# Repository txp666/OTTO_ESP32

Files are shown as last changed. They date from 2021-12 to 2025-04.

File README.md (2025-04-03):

# OTTO_ESP32  此仓库弃用，建议制作 小智AI版本
 OTTO机器人加入esp32蓝牙遥控和屏幕

[OTTO开源地址](https://github.com/OttoDIY)

[OTTO官网](https://www.ottodiy.com/)

[OTTO组装教程](https://tech.limuqiao.com/archives/24.html)

ESP32开发环境：[VScode+PlatformIO](https://blog.csdn.net/qlexcel/article/details/121527415)

安装存储卡、硬件参考[Peak](https://github.com/peng-zhihui/Peak)

采购参考请看HardWare文件夹

[【自制】通过学习稚晖君的Peak做个OTTO机器人【教程】_哔哩哔哩_bilibili](https://www.bilibili.com/video/BV1aq4y1m7bJ?spm_id_from=333.999.0.0)

[【自制】otto机器人移植ESP32+ESP32蓝牙遥控【演示】_哔哩哔哩_bilibili](https://www.bilibili.com/video/BV1ua41167SG?spm_id_from=333.999.0.0)

# 联系我：

若有bug或问题请联系我

QQ:1104428360

邮箱：771454616@qq.com

# 版本更新说明：
**2022/7/8**

程序更新动图播放、无遥控，打开开关跳舞

**2022/5/20**

Model更新、开sd卡槽、头部改变形状

**2022/5/19**

pcb添加sd卡

封装更换为0603（方便新手焊接）

放弃使用蓝牙遥控器

**2022/1/20**

Model->body 增加了开关处的壁厚

HardWare->OTTO修改了舵机排针位置

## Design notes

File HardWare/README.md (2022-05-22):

# 打样：

OTTO的PCB厚度一定要1mm

# 采购：

[电池[303450/500毫安]](https://item.taobao.com/item.htm?spm=a1z09.2.0.0.99af2e8d9avaY7&id=528235852444&_u=p20q7cgbef60)

| Comment | Description | Designator | Footprint | Quantity |
| --- | --- | --- | --- | --- |
| [RAINSUN](https://item.taobao.com/item.htm?spm=a1z09.2.0.0.7caa2e8dtIdJCk&id=558699169012&_u=p20q7cgb121e) | 天线 | A1 | ANT-Rainsun-AN5120 | 1 |
| 0.1uF | Capacitor | C1, C2, C3, C5, C8,  C12, C13 | C0603 | 7 |
| 10uF | Capacitor | C4, C6, C14 | C0603 | 3 |
| 1uF | Capacitor | C7 | C0603 | 1 |
| 4.7UF | Capacitor | C9, C11 | C0603 | 2 |
| 104/0.1uf/100nf | Capacitor | C10 | C0603 | 1 |
| red | led | D1 | LED0603 | 1 |
| [GP26-2520WV-3P](https://item.taobao.com/item.htm?spm=a1z10.3-c-s.w4002-21223910208.18.40c96a4b8Tk4yR&id=540755607552) | 2.54间距3p排针 | H1, H2, H3, H4 | PIN2.54_1*3 | 4 |
| [AO3400A](https://item.taobao.com/item.htm?spm=a1z10.3-c-s.w4002-21223910208.9.43706a4biknwUv&id=522574089119) | N-MOS | Q1, Q2 | SOT23-3 | 2 |
| 0R | Resistor | R2 | R0603 | 1 |
| 200R | Resistor | R3 | R0603 | 1 |
| 12K | Resistor | R4, R5 | R0603 | 2 |
| 10K | Resistor | R6, R14, R15, R16,  R17, R18, R19, R20 | R0603 | 8 |
| 5.1K | Resistor | R7, R8 | R0603 | 2 |
| 100K | Resistor | R9, R10 | R0603 | 2 |
| 2K | Resistor | R11 | R0603 | 1 |
| 1K | Resistor | R12 | R0603 | 1 |
| 10R | Resistor | R13 | R0603 | 1 |
| [LCD-240x240](https://item.taobao.com/item.htm?spm=a1z09.2.0.0.49222e8dUDZH8g&id=600653923469&_u=k20q7cgbb84c) | 显示屏 | S1 | LCD-240x240-FlUSH-154 | 1 |
| [TF](https://item.taobao.com/item.htm?spm=a1z09.2.0.0.49222e8dUDZH8g&id=522573245737&_u=k20q7cgb84a3) | 8脚自弹 | TF1 | TF-SOCKET | 1 |
| [CH340C](https://item.taobao.com/item.htm?spm=a1z10.3-c-s.w4002-21223910208.17.63036a4b79TAGX&id=572355836370) | | U1 | SOP-16_L10.0-W3.9-P1.27-LS6.0-BL | 1 |
| [XC6210B332MR  3.3](https://item.taobao.com/item.htm?spm=a1z09.2.0.0.49222e8dUDZH8g&id=559236610497&_u=k20q7cgb0854) | LDO | U2 | SOT23-5 | 1 |
| [MCP73831](https://item.taobao.com/item.htm?spm=a1z09.2.0.0.49222e8dUDZH8g&id=654241859685&_u=k20q7cgb58eb) | 线性充电管理控制器 | U3 | SOT23-5 | 1 |
| [ESP32_SIP](https://item.taobao.com/item.htm?spm=a1z09.2.0.0.31e32e8dKrcqT8&id=635409903966&_u=k20q7cgb6abe) | | U4 | QFN-48_7X7 | 1 |
| [DET402](https://item.taobao.com/item.htm?spm=a1z09.2.0.0.7caa2e8dtIdJCk&id=633598764121&_u=p20q7cgb2b73) | 贴片蜂鸣器 | U6 | DET402 | 1 |
| [Type-C](https://item.taobao.com/item.htm?spm=a1z10.3-c-s.w4002-21223910208.14.17886a4bo9NVsb&id=573090887123) | | USB1 | Type-C-TOP | 1 |
| [S8050](https://item.taobao.com/item.htm?spm=a1z10.3-c-s.w4002-21223910208.11.44ff6a4b9TY6dB&id=522577964105) | Surface mount NPN  transistor, package SOT-23 | VT1, VT2 | SOT23-3 | 2 |

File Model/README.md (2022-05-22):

推荐嘉立创的3D打印平台

Foot与Leg打两份
_3BX6_L~L)B@UKT_ZN(}D{A

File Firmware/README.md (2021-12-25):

在VScode中安装PlatformIO插件

打开文件夹即可



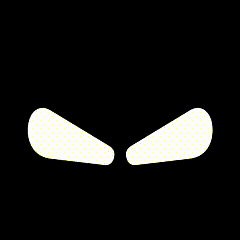
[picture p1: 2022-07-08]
Firmware/Otto-ESP32-fw/include/anger2/images/anger2_80.png

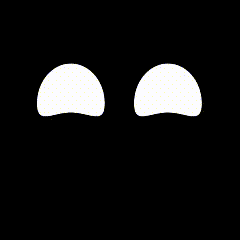
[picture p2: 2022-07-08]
Firmware/Otto-ESP32-fw/include/excited/images/excited1_27.png

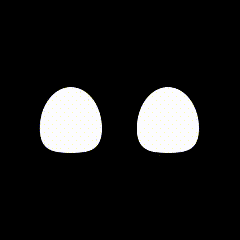
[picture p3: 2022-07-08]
Firmware/Otto-ESP32-fw/src/Images/excited/images/excited1_12.png

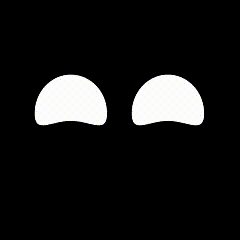
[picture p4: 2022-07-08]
Firmware/Otto-ESP32-fw/include/excited/images/excited1_31.png

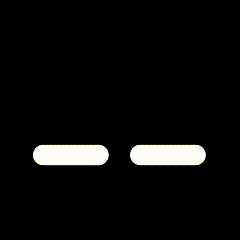
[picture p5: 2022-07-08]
Firmware/Otto-ESP32-fw/include/anger1/images/anger1-10.png

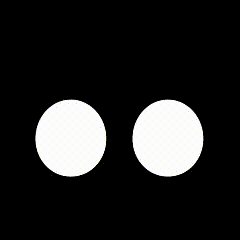
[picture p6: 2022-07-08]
Firmware/Otto-ESP32-fw/src/Images/excited/images/excited1_5.png

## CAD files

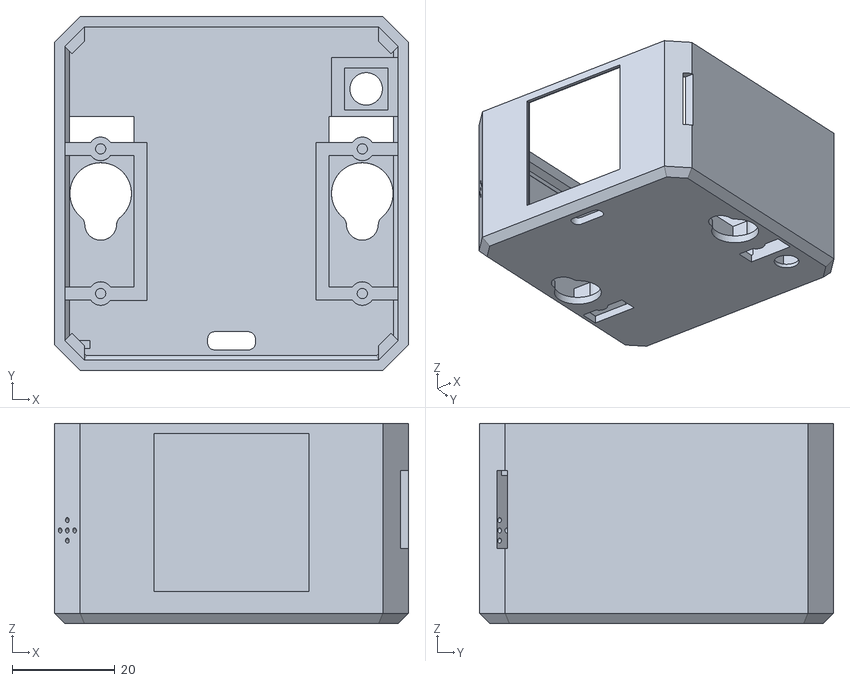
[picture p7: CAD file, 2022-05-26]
Model/Body.stl
69.0 x 69.0 x 39.0

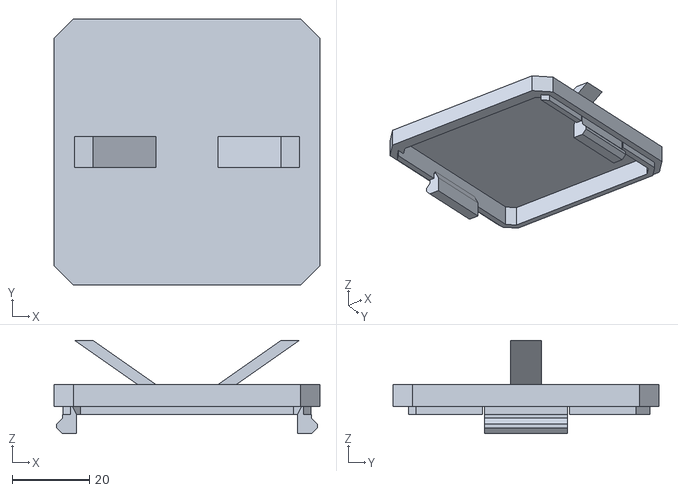
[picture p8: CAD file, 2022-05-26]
Model/Head.stl
69.0 x 69.0 x 24.2

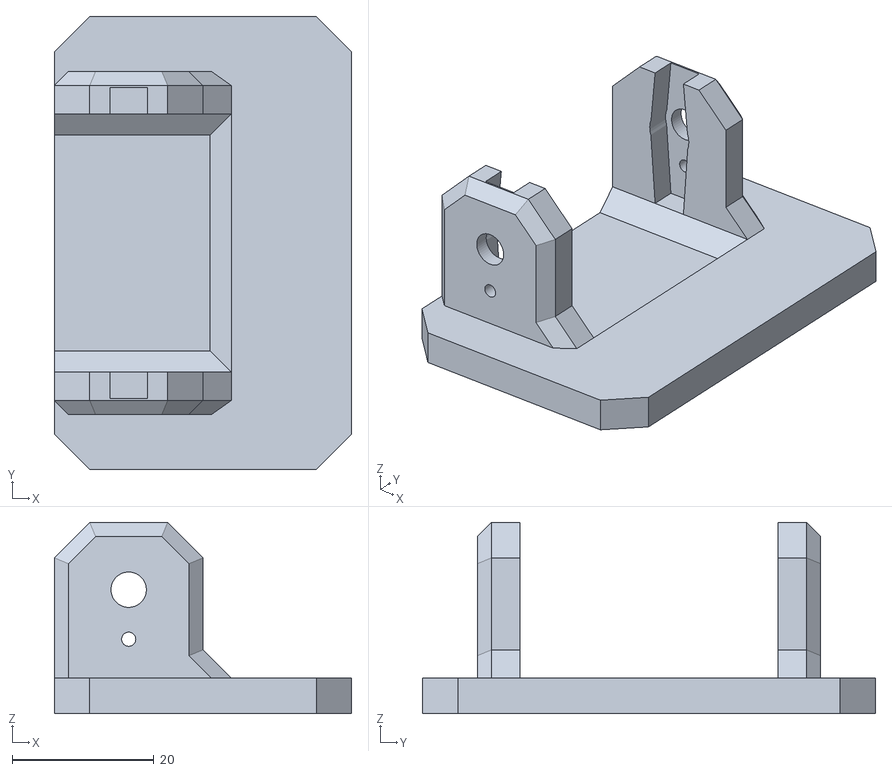
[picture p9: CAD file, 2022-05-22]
Model/Foot.stl
42.0 x 64.0 x 27.0

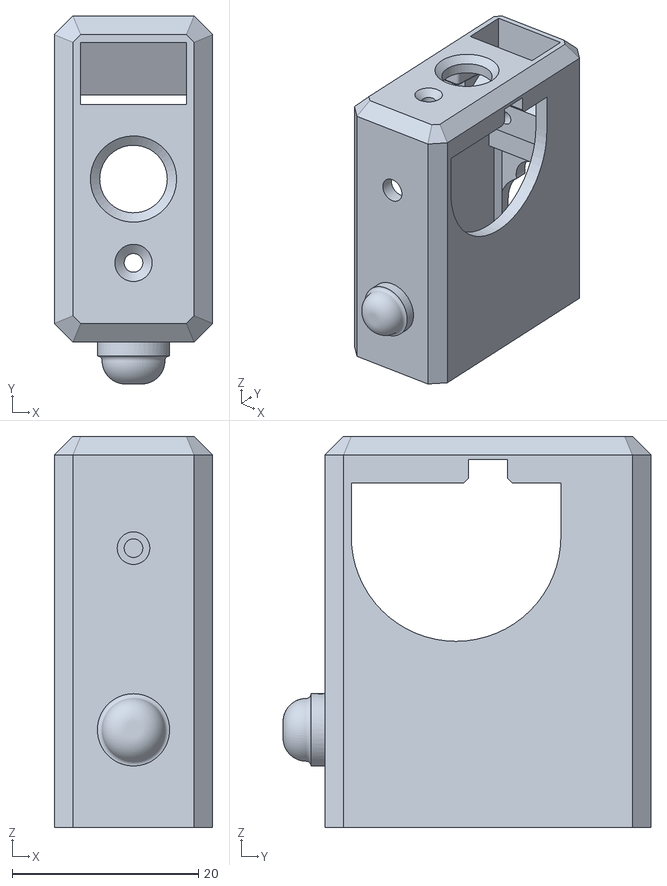
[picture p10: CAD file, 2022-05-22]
Model/Leg.stl
17.0 x 39.5 x 42.0

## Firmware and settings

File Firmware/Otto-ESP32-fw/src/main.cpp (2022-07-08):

//--------------------------------------------------------------------------------------------------------------------------------------------------------------------
//-- Otto DIY App Firmware Version 13 with standard baudrate of 9600 for Bluetooth BLE modules.
//-- Otto DIY invests time and resources providing open source code and hardware,
//-- please support by purchasing kits from (https://www.ottodiy.com)
//-- Make sure to have installed all libraries: https://github.com/OttoDIY/OttoDIYLib
//-----------------------------------------------------------------
//-- If you wish to use this software under Open Source Licensing, you must contribute all your source code to the community and all text above must be included in any redistribution
//-- in accordance with the GPL when your application is distributed. See http://www.gnu.org/copyleft/gpl.html
//---------------------
/*
         ---------------
        |     O   O     |
        |---------------|
YR 33==> |               | <== YL 19
         ---------------
            ||     ||
RR 32==>   -----   ------  <== RL 21
         |-----   ------|
*/
//#include <SerialCommand.h>
#include <lvgl.h>
#include "HAL/HAL.h"
#include "Port/Display.h"
#include "App/App.h"
#include "App/image.h"
#include <Otto.h>

Otto Otto;

#define LeftLeg 19
#define RightLeg 33
#define LeftFoot 21
#define RightFoot 32
#define Buzzer 25

void setup()
{

    Otto.init(LeftLeg, RightLeg, LeftFoot, RightFoot, true, Buzzer); // Set the servo pins and Buzzer pin
    Otto.home();
    HAL::Init();
    Port_Init();
    App_Init();

    // anger1_animing();
    excited1_animing();
    // anger2_animing();
    Otto.sing(S_happy);
    delay(200);
}
void OttoDancing();

void loop()
{
    HAL::Update();
    delay(20);
    OttoDancing();
}

void OttoDancing()
{
    Otto.walk(1, 3000, 1);  // 2 steps, "TIME". IF HIGHER THE VALUE THEN SLOWER (from 600 to 1400), 1 FORWARD
    Otto.walk(2, 1000, -1); // 2 steps, T, -1 BACKWARD
    Otto.turn(2, 1000, 1);  // 3 steps turning LEFT
    Otto.home();
    delay(100);
    Otto.turn(2, 1000, -1); // 3 steps turning RIGHT
    Otto.bend(1, 500, 1);   // usually steps =1, T=2000
    Otto.bend(1, 2000, -1);
    Otto.shakeLeg(1, 1500, 1);
    Otto.home();
    delay(100);
    Otto.shakeLeg(1, 2000, -1);
    Otto.moonwalker(3, 1000, 25, 1);  // LEFT
    Otto.moonwalker(3, 1000, 25, -1); // RIGHT
    Otto.crusaito(2, 1000, 20, 1);
    Otto.crusaito(2, 1000, 20, -1);
    delay(100);
    Otto.flapping(2, 1000, 20, 1);
    Otto.flapping(2, 1000, 20, -1);
    delay(100);
    Otto.swing(2, 1000, 20);
    Otto.tiptoeSwing(2, 1000, 20);
    Otto.jitter(2, 1000, 20); // (small T)
    Otto.updown(2, 1500, 20); // 20 = H "HEIGHT of movement"T
    Otto.ascendingTurn(2, 1000, 50);
    Otto.jump(1, 2000);
    Otto.home();
}

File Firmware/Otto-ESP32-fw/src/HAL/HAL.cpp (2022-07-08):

#include "HAL/HAL.h"
#include "App/Configs/Version.h"


#define DISP_HOR_RES CONFIG_SCREEN_HOR_RES
#define DISP_VER_RES CONFIG_SCREEN_VER_RES
#define DISP_BUF_SIZE CONFIG_SCREEN_BUFFER_SIZE
extern lv_color_t *lv_disp_buf_p;

void HAL::Init()
{
    Serial.begin(115200);
    Serial.println(VERSION_FIRMWARE_NAME);
    Serial.println("Version: " VERSION_SOFTWARE);
    Serial.println("Author: " VERSION_AUTHOR_NAME);

    // Move the malloc process to Init() to make sure that the largest heap can be used for this buffer.
    lv_disp_buf_p = static_cast<lv_color_t *>(malloc(DISP_BUF_SIZE * sizeof(lv_color_t)));
    if (lv_disp_buf_p == nullptr)
        LV_LOG_WARN("lv_port_disp_init malloc failed!\n");
    HAL::Power_Init();
    HAL::Backlight_Init();

    HAL::SD_Init();
}

void HAL::Update()
{
    HAL::Power_Update();
    __IntervalExecute(HAL::SD_Update(), 500);
}

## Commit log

2021-12-25 创建 Otto DIY.apk
2021-12-25 上传gerber打样
    [ESP32-PicoDK-副本.PrjPCB, ESP32-PicoDK.PcbDoc, ESP32遥控.PrjPCB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]
2021-12-25 更新 README.md
2021-12-25 创建 README.md
2021-12-25 更新README
2021-12-25 更新 Body.stl
    [Body.stl]
2022-01-20 修改舵机排针位置
    [OTTO_ESP32.PcbDoc, OTTO_ESP32.PrjPCB]
2022-01-20 更新 main.cpp
    修改前后方向
2022-05-19 ADD sd 0402->0603
    [Main.SchDoc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]
2022-05-19 remove remote
    [Drawing1.dwg, ESP32遥控.DWG, ESP32遥控.PrjPCB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]
2022-05-20 update model
    [Body.stl, Foot.stl, Head.stl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]
2022-05-20 Add Bom
2022-05-22 添加丝印
    [OTTO_ESP32.PcbDoc, OTTO_ESP32.PrjPCB]
2022-05-26 装配细节修改
    [Body.stl, Head.stl]
2022-07-08 动图播放
2022-08-27 适配最新的platformio版本
